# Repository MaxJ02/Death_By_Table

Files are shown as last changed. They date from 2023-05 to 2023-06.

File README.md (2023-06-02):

# School project - Autonomous RC-car - ELA22, YRGO

## Introduction

The university of YRGO anually hosts an autonomous rc-car grand prix between the two first year electronic-engineering classes. The classes are split into three
groups per class, where each group is tasked with the goal to design and construct a fully autonomous rc car to compete in the YRGO grand prix of that year.
The car races three competing cars simoultaneously on the track where the car that finishes the most laps in 3 minutes is crowned the winner.
The grand prix consists of a group stage, quarter finals, semi finals and the final.

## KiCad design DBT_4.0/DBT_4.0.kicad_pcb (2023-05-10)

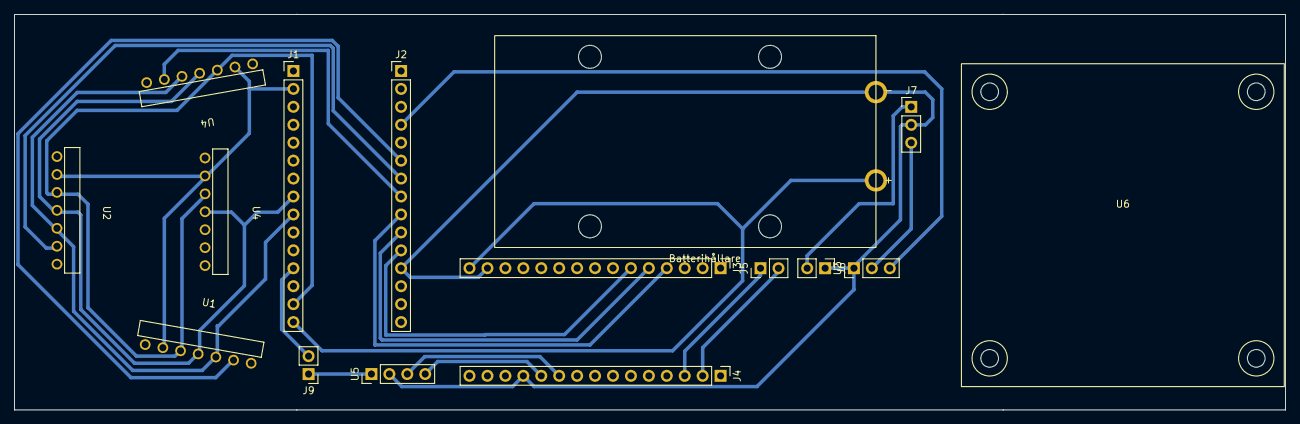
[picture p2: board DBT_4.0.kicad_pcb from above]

Board: 2 copper layers, 180.0 x 56.0 mm, 16 parts (0 on the bottom side), 29 nets.

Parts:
Batterihållare: Batterihållare_9V_projekt_2
J1, J2, J3, J4: Conn_01x15; PinHeader_1x15_P2.54mm_Vertical
J5, J6, J9: Conn_01x02; PinHeader_1x02_P2.54mm_Vertical
J7: Conn_01x03; PinHeader_1x03_P2.54mm_Vertical
U1, U2, U4, U4#2: VL53L1X; VL53L1x
U3: Servo; PinHeader_1x03_P2.54mm_Vertical
U5: Start_module; PinHeader_1x04_P2.54mm_Vertical
U6: H-brygga

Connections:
+3.3V: J1.2, J3.2, U1.2 (VIN), U2.2 (VIN), U4.2 (VIN), U4#2.2 (VIN)
+5V: J1.12, J3.12, J7.3, J9.2, U3.2 (Vin/+)
+9V: Batterihållare.1, J1.15, J3.15
+BATT: J6.2, J7.1
/*D3: J4.10, U5.3 (Start)
/*D5: J2.8, J4.8, U4.6 (XSHUNT)
/*D6: J2.7, J4.7, U2.6 (XSHUNT)
/*D9: J2.4, J4.4, U3.3 (Signal)
/*D10/SS: J2.3, J4.3, J5.1
/*D11/MOSI: J2.2, J4.2, J5.2
/A0/D4: J2.9, J3.4
/A1/*D3: J2.10, J3.5
/A2/D2: J2.11, J3.6
/A3: J1.7, J3.7
/A4/SDA: J1.8, J3.8, U1.4 (SDA), U2.4 (SDA), U4.4 (SDA), U4#2.4 (SDA)
/A5/SCL: J1.9, J3.9, U1.5 (SCL), U2.5 (SCL), U4.5 (SCL), U4#2.5 (SCL)
/A6: J1.10, J3.10
/A7: J1.11, J3.11
/AREF: J1.3, J3.3
/D0/RX: J2.14, J4.14
/D1/TX: J2.15, J4.15
/D2: J4.11, U5.4 (Kill)
/D7: J2.6, J4.6, U1.6 (XSHUNT)
/D8: J2.5, J4.5, U4#2.6 (XSHUNT)
/D12/MISO: J2.1, J4.1
/D13/SCK: J1.1, J3.1
/~RESET: J1.13, J2.13, J3.13, J4.13
GND: Batterihållare.2, J1.14, J2.12, J3.14, J4.12, J6.1, J7.2, U1.3 (GND), U2.3 (GND), U3.1 (GND/-), U4.3 (GND), U4#2.3 (GND), U5.2 (GND)
unnamed: J9.1, U5.1 (VCC)

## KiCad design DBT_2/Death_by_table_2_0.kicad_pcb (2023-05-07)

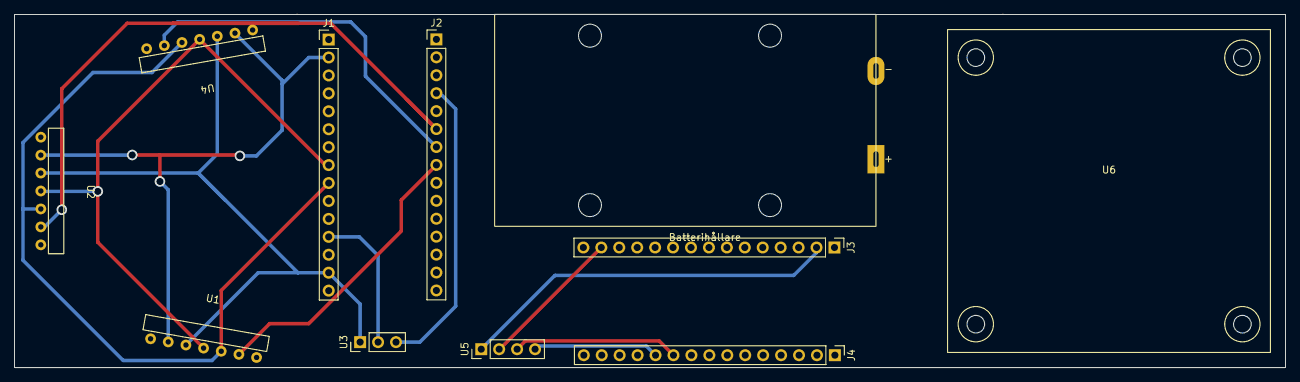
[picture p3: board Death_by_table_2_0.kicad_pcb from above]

Board: 2 copper layers, 180.0 x 50.0 mm, 11 parts (0 on the bottom side), 28 nets.

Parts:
Batterihållare: Batterihållare_9V_projekt_2
J1, J2, J3, J4: Conn_01x15; PinHeader_1x15_P2.54mm_Vertical
U1, U2, U4: VL53L1X; VL53L1x
U3: Servo; PinHeader_1x03_P2.54mm_Vertical
U5: Start_module; PinHeader_1x04_P2.54mm_Vertical
U6: H-brygga

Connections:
+3.3V: J1.2, J3.2, U1.2 (VIN), U2.2 (VIN), U4.2 (VIN), U5.1 (VCC)
+5V: J1.12, J3.12, U3.2 (Vin/+)
+6V: J1.15, J3.15
/*D3: J2.10, J4.10, U5.3 (Start)
/*D5: J2.8, J4.8, U1.6 (XSHUNT)
/*D6: J2.7, J4.7, U4.6 (XSHUNT)
/*D9: J2.4, J4.4, U3.3 (Signal)
/*D10/SS: J2.3, J4.3
/*D11/MOSI: J2.2, J4.2
/A0: J1.4, J3.4
/A1: J1.5, J3.5
/A2: J1.6, J3.6
/A3: J1.7, J3.7
/A4/SDA: J1.8, J3.8, U1.4 (SDA), U2.4 (SDA), U4.4 (SDA)
/A5/SCL: J1.9, J3.9, U1.5 (SCL), U2.5 (SCL), U4.5 (SCL)
/A6: J1.10, J3.10
/A7: J1.11, J3.11
/AREF: J1.3, J3.3
/D0/RX: J2.14, J4.14
/D1/TX: J2.15, J4.15
/D2: J2.11, J4.11, U5.4 (Kill)
/D4: J2.9, J4.9
/D7: J2.6, J4.6, U2.6 (XSHUNT), U4.1 (VDD)
/D8: J2.5, J4.5
/D12/MISO: J2.1, J4.1
/D13/SCK: J1.1, J3.1
/~RESET: J1.13, J2.13, J3.13, J4.13
GND: J1.14, J2.12, J3.14, J4.12, U1.3 (GND), U2.3 (GND), U3.1 (GND/-), U4.3 (GND), U5.2 (GND)

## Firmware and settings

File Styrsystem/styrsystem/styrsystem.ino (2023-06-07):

#include "header.hpp"

#define RUN_SIGNAL 4
#define BOOST 3
#define TURN 2
#define BOOST_COUNT 10

// Servo variables
Servo myServo;
double angle;
struct servo servo1;

// Sensor variables
// The Arduino pin connected to the XSHUT pin of each sensor.
const uint8_t xshutPins[] = {5,6,7};

// The number of sensors in your system.
const uint8_t sensorCount = sizeof(xshutPins) / sizeof(uint8_t);

VL53L1X sensors[sensorCount];
double reverse_direction[10];
bool boost = false;
bool turn = false;
uint16_t timer_counter = 0;
uint16_t boost_counter = 0;
static double frontdistance = 0;




/********************************************************************************
* servo_run: Reads input values for left and right TOF sensor, regulates the
*            servo angle according to the input and prints the result in the
*            terminal.
*
*            - self: Reference to the servo.
********************************************************************************/
void servo_run(struct servo* self)
{
   pid_regulate(&self->pid, servo_input_mapped(self));
   angle = self->pid.output;
   //angle = map(angle,0,180,0,1023);

   return;
}

void check_boost()
{
    if(boost == true)
    {
    boost_counter++;
    if(boost_counter >= 2)
    {
      boost_counter = 0;
      boost = false;
      digitalWrite(BOOST, LOW);
    }
    }
    else if(frontdistance < 400 && frontdistance > 200)
    {
       boost = true;
       digitalWrite(BOOST, HIGH);
    }
  else boost_counter = 0;
  // Serial.print("Frontlow: ");
  // Serial.print(frontdistance);
  // Serial.print('\t');
}

void get_front_distance()
{
  frontdistance = sensors[1].read();
}

/********************************************************************************
* print_values: Skriver ut värden på sensorer och vilken vinkeln som servon
*               är inställd mot. Skriver även ut om bil är i reverse.
********************************************************************************/
void print_values()
{
  Serial.print("Left: ");
  Serial.print(servo1.tof_left.val);
  Serial.print('\t');
  Serial.print("Right: ");
  Serial.print(servo1.tof_right.val);
  Serial.print('\t');
  Serial.print("Angle: ");
  Serial.print(servo1.pid.output);
  Serial.print('\t');
  Serial.print("Frontlow: ");
  Serial.print(sensors[1].read());
  // Serial.print('\t');
  // Serial.print("Turn?");
  // Serial.print(turn);

  // Serial.print('\t');
  // Serial.print("Fronthigh: ");
  // Serial.print(sensors[3].read());
  // Serial.print('\t');
  Serial.println();
}

void setup()
{
  //Kommunikations pinnar till andra arduinon.
  pinMode(RUN_SIGNAL, INPUT);
  pinMode(BOOST, OUTPUT);
  pinMode(TURN, OUTPUT);

 // Servo setup
  myServo.attach(9);

  // Sensor setup
  while (!Serial) {}
  Serial.begin(115200);
  Wire.begin();
  Wire.setClock(400000); // use 400 kHz I2C

  for (uint8_t i = 0; i < sensorCount; i++)
  {
    pinMode(xshutPins[i], OUTPUT);
    digitalWrite(xshutPins[i], LOW);
  }

  for (uint8_t i = 0; i < sensorCount; i++)
  {
    pinMode(xshutPins[i], INPUT);
    delay(10);

    sensors[i].setTimeout(500);
    if (!sensors[i].init())
    {
      Serial.print("Failed to detect and initialize sensor ");
      Serial.println(i);
      while (1);
    }

    sensors[i].setAddress(0x2A + i);

    sensors[i].startContinuous(100);
  }

  //PID initiering på servo
  servo_init(&servo1,95,         // servons "mitt" Ändra inte.
              60,130,     // Min & max vinklar
              0,1024,     // min max sensor avstånd
              0.50,0.001, 1.11); // PID default är 0.75,0.01, 0.6 // 0.7  ////// 0.65,0.005, 1

  wdt_disable();  /* Disable the watchdog and wait for more than 2 seconds */
  delay(3000);  /* Done so that the Arduino doesn't keep resetting infinitely in case of wrong configuration */
  wdt_enable(WDTO_2S);
}

// 0.55,0.005, 1.15 Funkar sådär
//0.55,0.001, 1.15
//0.50,0.001, 1.11 // HASTIGHET 35

void loop()
{
  while(digitalRead(RUN_SIGNAL)==1)
  {
      servo1.tof_left.val = sensors[2].read();
      servo1.tof_right.val = sensors[0].read();
      servo_run(&servo1);
      if(angle < 85 || angle > 105) // 1 varv if(angle < 80 || angle > 110) HASTIGHET 38 //// if(angle < 85 || angle > 105) hastighet 35/23
      {
        digitalWrite(TURN, HIGH);
        //turn = true;
        set_pid(&servo1.pid, 0.60,0.005, 1);
        get_front_distance();
        check_reverse();
      }
      else
      {
        digitalWrite(TURN, LOW);
        //turn = false;
        set_pid(&servo1.pid, 0.50, 0.001, 1.11);
        get_front_distance();
        check_boost();
        check_reverse();
      }
      myServo.write(angle);
      wdt_reset();
      //print_values();
    //}
  }
  myServo.write(95);
}

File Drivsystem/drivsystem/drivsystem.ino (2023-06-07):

/********************************************************************************
* Drivsystem: Kod för att styra körriktning och motorhastighet via: 
*             Motordrivare L298 dubbel H-Brygga 5-35V 2A.
*             Samt Remotstart och stop.
********************************************************************************/
#define KillSwitch 2 // Pin nummer för killswitch på startmodul
#define RemoteStart 3 // Pin nummer för start modulens remote start
#define StartSignal A0 // Pin nummer som signalerar till styr arduino att starta
#define BOOST A1     // pin nummer för boost funktion.
#define TURN A2       // pin nummer för att sakta ner vid sväng.
#define MOTOR_FORWARD  10 // pin nummer för motor_forward pin
#define MOTOR_BACKWARD 11  // pin nummer för motor_backward pin

static inline void motor_forward(const uint8_t pwm_value)
{
  analogWrite(MOTOR_FORWARD, pwm_value);
  digitalWrite(MOTOR_BACKWARD, 0);
}

static inline void motor_backward(const uint8_t pwm_value)
{
  digitalWrite(MOTOR_FORWARD, 0);
  analogWrite(MOTOR_BACKWARD, pwm_value);
}

static inline void motor_wait_for_start(void)
{
  while ((digitalRead(RemoteStart) && digitalRead(KillSwitch)) == 0);
  digitalWrite(StartSignal, 1);
  return;
}

static inline void boost(int speed)
{
  set_speed(speed);
  delay(500);
}

// Initierar pinnar för motorstyrning samt startmodul.
void setup()
{
  pinMode(RemoteStart, INPUT);
  pinMode(KillSwitch, INPUT);
  pinMode(StartSignal, OUTPUT);
}

//Sätter motorhastighet i procent mellan 0-100%
void set_speed(uint8_t speed)
{
  speed = map(speed, 0,100,0,255);
  analogWrite(MOTOR_FORWARD, speed);
  digitalWrite(MOTOR_BACKWARD, 0);
}


void loop()
{
  motor_wait_for_start(); 
  // set_speed(50);
  // delay(100);
  while((digitalRead(RemoteStart) && digitalRead(KillSwitch)) == 1)
  {
    if((digitalRead(BOOST) == 1))
    {
      // if(digitalRead(TURN)==1)
      // {
      //   motor_backward(80);
      //   delay(500);
      // }
      // else
      //{ 
       set_speed(80);
       delay(50);
      //}   
    }
    else if(digitalRead(TURN)==1)
    {
      set_speed(20);
    }
    else
    {
      set_speed(35);// 70 var default med svagare LIPO, 60 Nuvarande default med 11v LIPO. Ny hastighet defualt 20. //37
    }
  }
  while((digitalRead(RemoteStart) && digitalRead(KillSwitch)) == 0)
  {
    digitalWrite(MOTOR_BACKWARD, 0);
    digitalWrite(MOTOR_FORWARD, 0);
    digitalWrite(StartSignal, 0);
  }
}

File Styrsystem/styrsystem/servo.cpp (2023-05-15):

/********************************************************************************
* servo.c: Includes drivers for PID controlled servos with TOF (Time Of Flight)
*          sensors to read the relative angle, followed by regulating the
*          servo angle towards the target.
********************************************************************************/
#include "header.hpp"
#include <VL53L1X.h>

/* Static functions: */
static inline void servo_print_relative_angle(const struct servo* self,
                                              FILE* ostream);

/********************************************************************************
* servo_init: Initiates servo with specified parameters. For instance, a target
*             of 90 degrees is center, a range of 0 - 180 degrees means all the
*             way to the left and to the right (0 = left, 180 = right).
*
*             - self        : Reference to the servo.
*             - target_angle: Target angle for servo.
*             - angle_min   : Minimum servo angle.
*             - angle_max   : Maximum servo angle.
*             - input_min   : Minimum input value for sensors.
*             - input_max   : Maximum input value for sensors.
*             - kp          : Proportional constant for PID controller.
*             - ki          : Integrate constant for PID controller.
*             - kd          : Derivate constant for PID controlle.
********************************************************************************/
void servo_init(struct servo* self,
                const double target_angle,
                const double angle_min,
                const double angle_max,
                const double input_min,
                const double input_max,
                const double kp,
                const double ki,
                const double kd)
{
   pid_init(&self->pid, target_angle, angle_min, angle_max, kp, ki, kd);
   tof_init(&self->tof_left, input_min, input_max);
   tof_init(&self->tof_right, input_min, input_max);
   return;
}

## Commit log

2023-04-19 Arduino kod
    Läser in sensor värden och styr servo med pid-styrning
2023-04-19 kombinerad styr och drift.
    Styr och sensor fungerar. Men driver inte motorn framåt. Pin 10 stannar låg.
2023-04-22 Reverse och kör signal
    Lade till en reverse funktion som vänder på styrningen när framsensorn känner av ett avstånd på mindre än 20cm i 3 sekunder. Avstånd och tiden borde finjusteras efter test på banan. När reverse variabeln blir true skickas det även en signal ut på pin8 som motor arduino kan använda för att vända motorriktning. Satte även pin 10 som inport för att känna av startsignal från motor arduinon, så att servo inte sitter och rycker innan racet börjar.
    [servo_och_sensorer.ino]
2023-05-04 Update and rename motorkod.ino to drivsystem.ino
    Updated from the current local version
2023-05-10 unzippad version av pcb4 för renlighet
    [DBT_4.0.kicad_pcb, DBT_4.0.kicad_sch]
2023-05-12 Update styrsystem.ino
    Uppdaterad för styrning av bilen med de nya däcken
